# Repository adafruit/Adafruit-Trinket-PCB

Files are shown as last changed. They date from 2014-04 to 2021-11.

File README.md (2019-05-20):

## Adafruit Trinket 3.3 and 5V Microcontroller PCBs
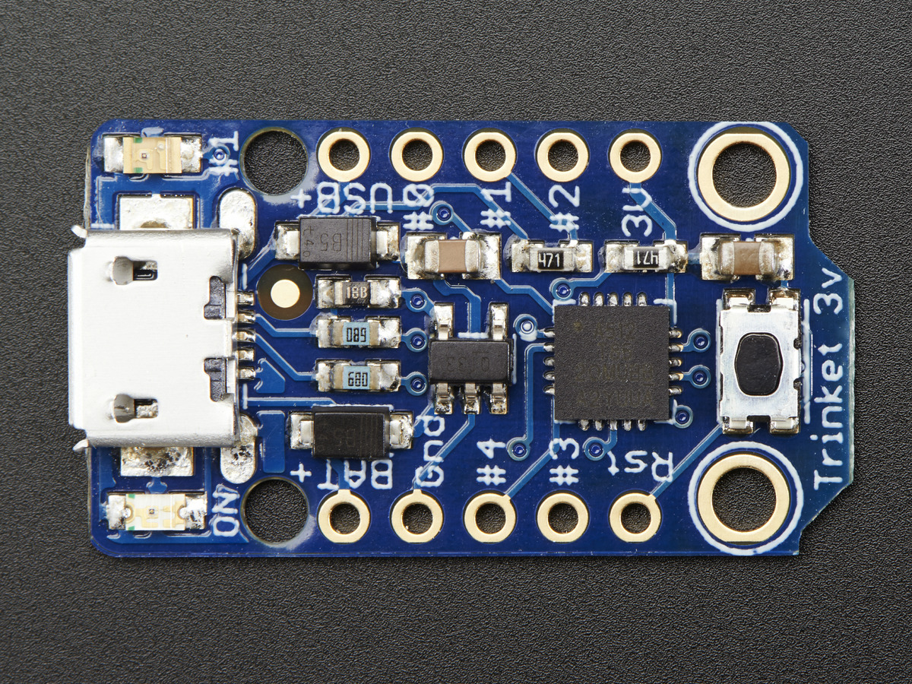
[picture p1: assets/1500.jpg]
&nbsp; 
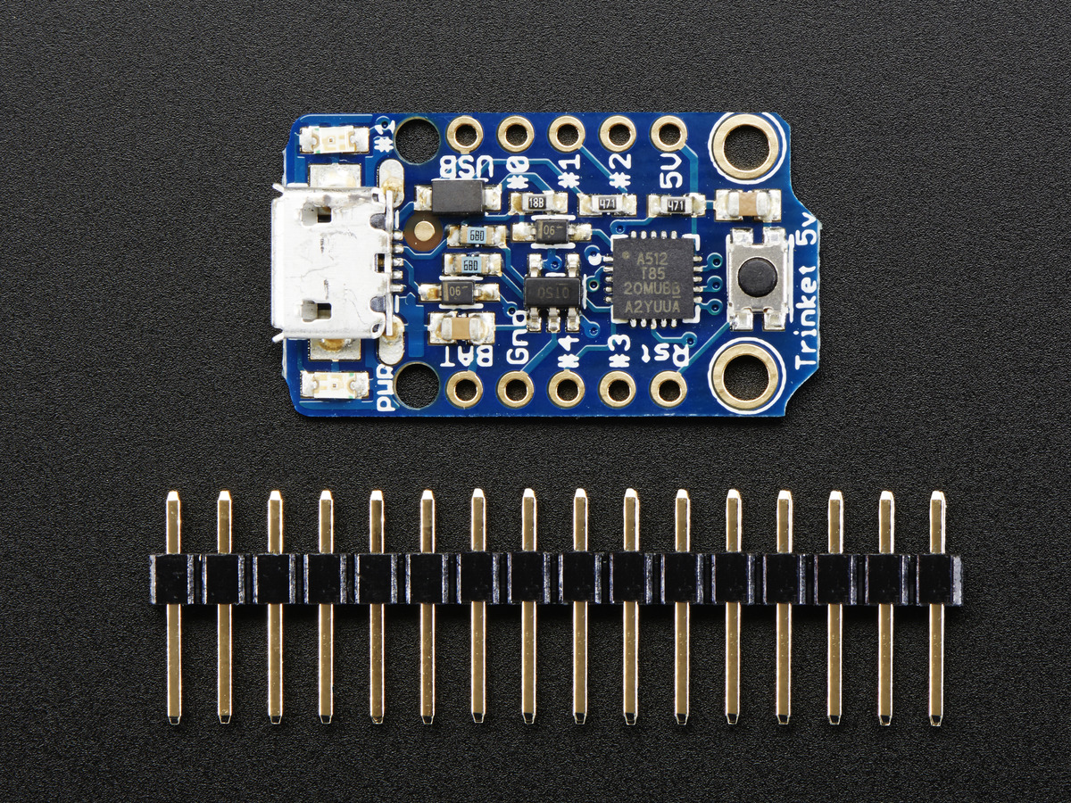
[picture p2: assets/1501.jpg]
<br />
Click to purchase from the Adafruit Shop:
- [Adafruit Trinket - Mini Microcontroller - 3.3V Logic - MicroUSB](https://www.adafruit.com/product/1500)
- [Adafruit Trinket - Mini Microcontroller - 5V Logic - MicroUSB](https://www.adafruit.com/product/1501)

Deprecation Warning: The Trinket bit-bang USB technique it uses doesn't work as well as it did in 2014, many modern computers won't work well. So while we still carry the Trinket so that people can maintain some older projects, we no longer recommend it. Please check out the **Trinket M0**. It has built-in USB, more capabilities, and is comparable in price!

Trinket may be small, but do not be fooled by its size! It's a tiny microcontroller board, built around the Atmel ATtiny85, a little chip with a lot of power. We wanted to design a microcontroller board that was small enough to fit into any project, and low cost enough to use without hesitation. Perfect for when you don't want to give up your expensive dev-board and you aren't willing to take apart the project you worked so hard to design. It's our lowest-cost arduino-IDE programmable board!

This is the CAD & PCB data for the Adafruit Trinket 3V & 5V. The PCB format is EagleCAD schematic and board layout
- https://www.adafruit.com/products/1500
- https://www.adafruit.com/products/1501

### License

Adafruit invests time and resources providing this open source design, please support Adafruit and open-source hardware by [purchasing products from Adafruit](https://www.adafruit.com)!

All text above must be included in any redistribution

Designed by Limor Fried/Ladyada for Adafruit Industries.
Creative Commons Attribution/Share-Alike, all text above must be included in any redistribution. 
See license.txt for additional information.

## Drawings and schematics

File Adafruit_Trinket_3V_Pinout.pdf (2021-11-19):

# Adafruit Trinket 3V

# https://www.adafruit.com/products/1500

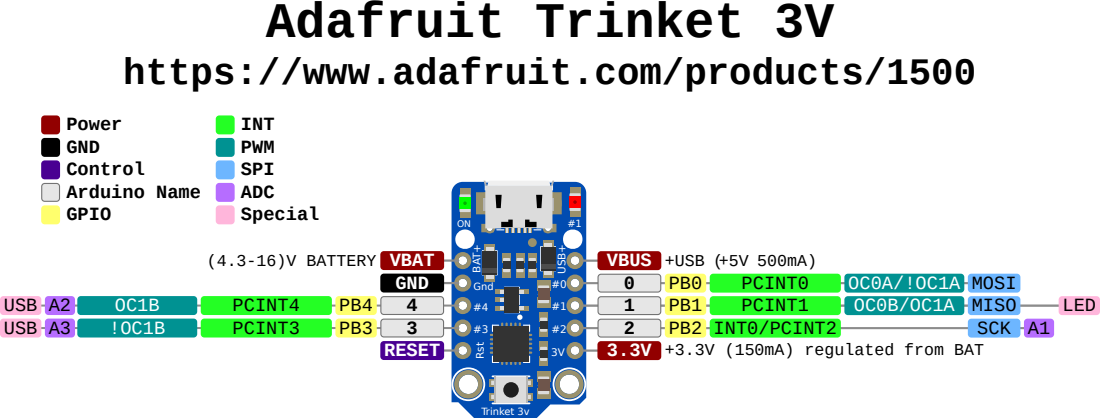
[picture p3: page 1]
#1 BAT+; USB+; Gnd; Rst; Trinket 3v; VBAT GND; RESET; VBUS; PCINT0; OC0A/!OC1A MOSI; PCINT1; OC0B/OC1A MISO; LED; PB2 INT0/PCINT2; SCK A1; USB A2; PCINT4; USB A3; PCINT3; Power GND Control Arduino Name GPIO; INT PWM SPI ADC Special; +USB (+5V 500mA); (4.3-16)V BATTERY

+3.3V (150mA) regulated from BAT

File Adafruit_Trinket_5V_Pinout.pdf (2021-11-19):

# Adafruit Trinket 5V

# https://www.adafruit.com/products/1501

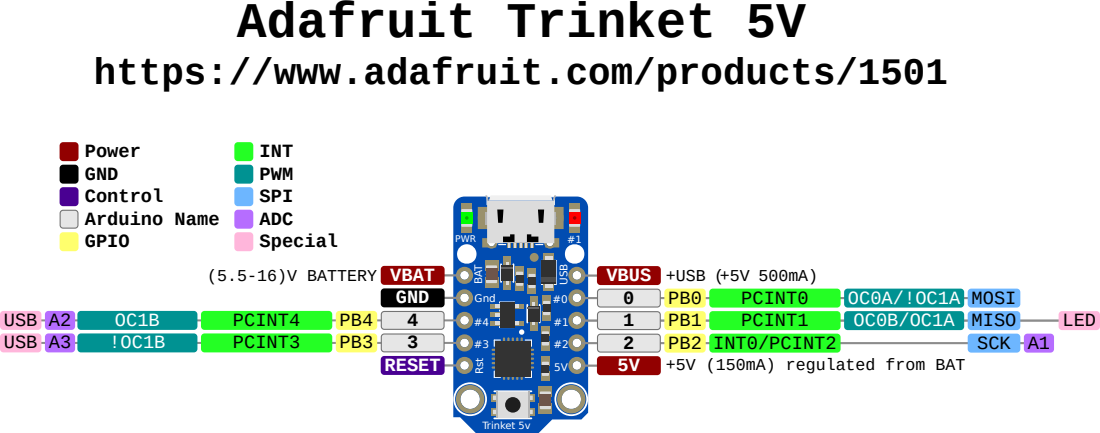
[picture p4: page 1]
PWR; #1 BAT; USB; Gnd; Rst #3; Trinket 5v; VBAT GND; USB A2; PCINT4; USB A3; PCINT3; RESET; VBUS; PCINT0; OC0A/!OC1A MOSI; PCINT1; OC0B/OC1A MISO; LED; PB2 INT0/PCINT2; SCK A1; Power GND Control Arduino Name GPIO; INT PWM SPI ADC Special; +USB (+5V 500mA); +5V (150mA) regulated from BAT; (5.5-16)V BATTERY

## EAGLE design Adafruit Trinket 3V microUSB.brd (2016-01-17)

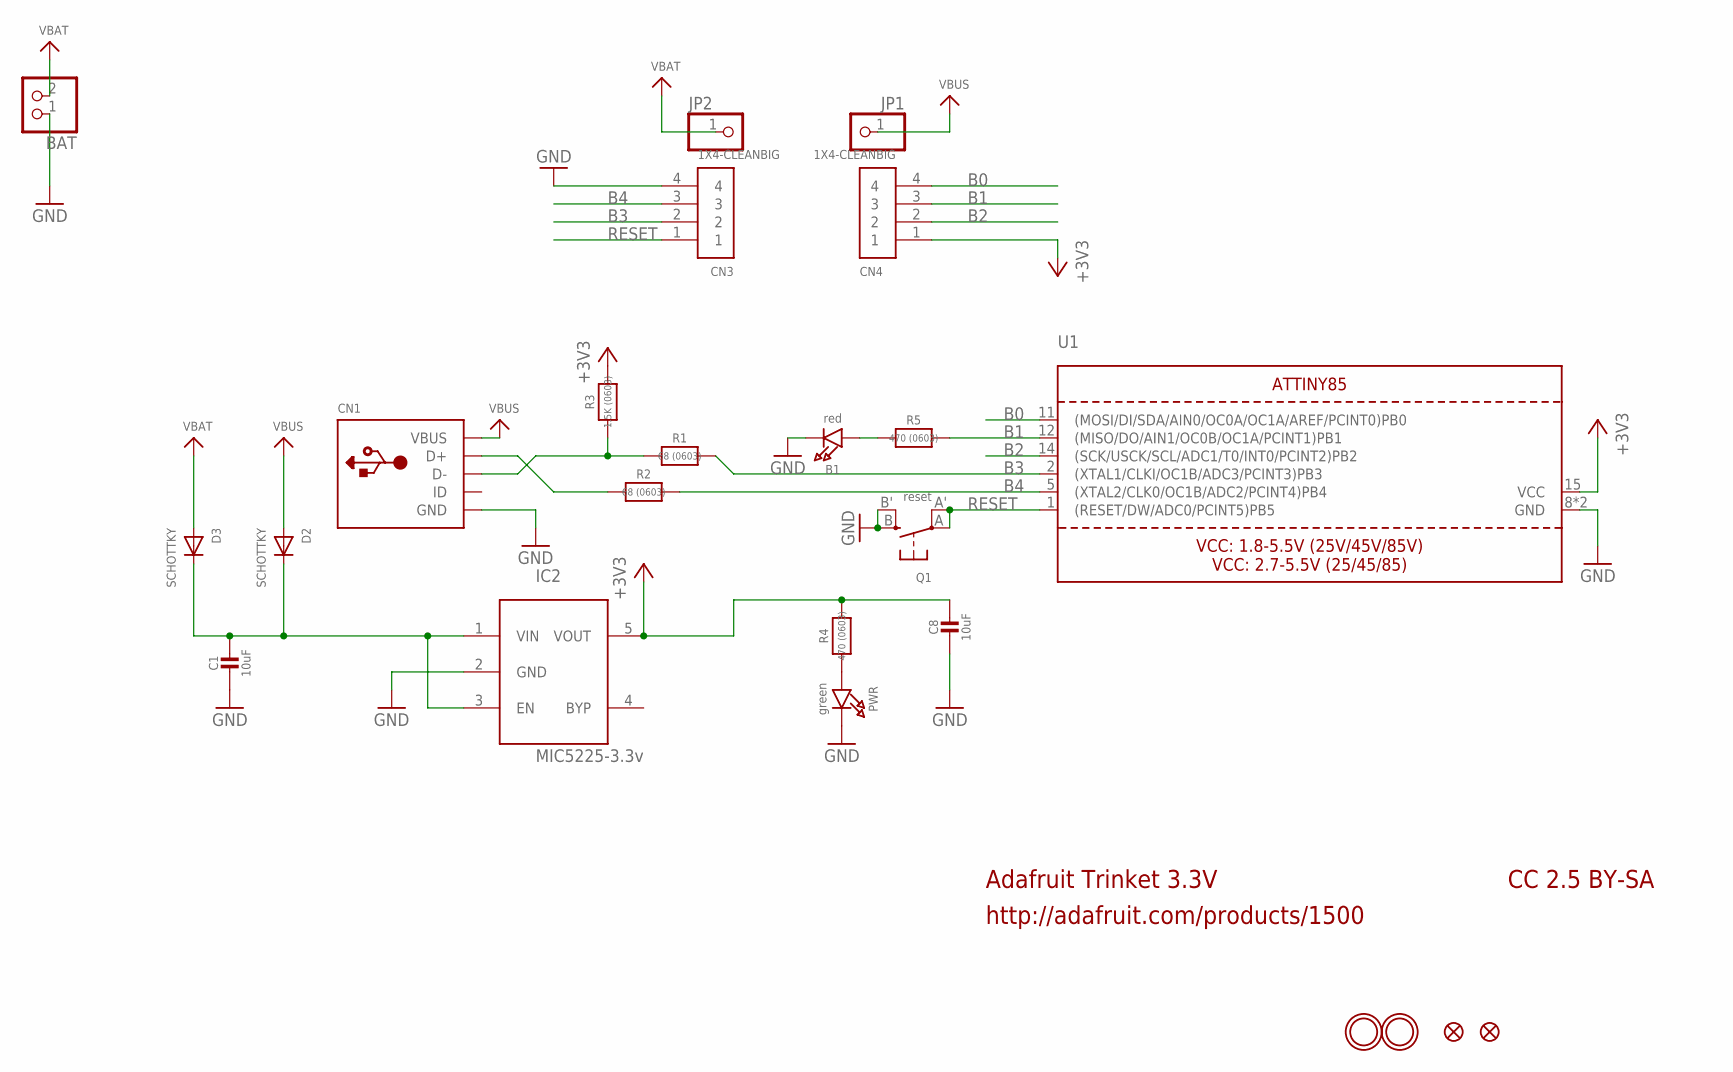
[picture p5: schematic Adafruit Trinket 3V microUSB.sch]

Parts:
B1: red; CHIPLED_0805_NOOUTLINE
BAT: CON_JST_PH_2PIN; JSTPH2
C1, C8: 10uF; 0805-NO
CN1: USBMICRO_20329; 4UCONN_20329
CN3, CN4: 1X4-CLEANBIG; 1X04-CLEANBIG
D2, D3: SCHOTTKY; SOD-123FL
IC2: MIC5225-3.3v; SOT23-5L
JP1, JP2: PINHD-1X1CB; 1X01-CLEANBIG
PWR: green; CHIPLED_0805_NOOUTLINE
Q1: reset; BTN_KMR2_4.6X2.8
R1, R2: 68 (0603); 0603-NO
R3: 1.5K (0603); 0603-NO
R4, R5: 470 (0603); 0603-NO
U1: ATTINY85; MLF20_4X4MM_0.5MM_ATMEL
U$1, U$6: FIDUCIAL""; FIDUCIAL_1MM
U$8, U$9: MOUNTINGHOLE2.0; MOUNTINGHOLE_2.0_PLATED

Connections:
+3V3: C8.1, CN4.1, IC2.5 (VOUT), R3.2, R4.2, U1.15 (VCC)
B0: CN4.4, U1.11 ((MOSI/DI/SDA/AIN0/OC0A/OC1A/AREF/PCINT0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)
B1: CN4.3, R5.2, U1.12 ((MISO/DO/AIN1/OC0B/OC1A/PCINT1)PB1)
B2: CN4.2, U1.14 ((SCK/USCK/SCL/ADC1/T0/INT0/PCINT2)PB2)
B3: CN3.2, R1.2, U1.2 ((XTAL1/CLKI/OC1B/ADC3/PCINT3)PB3)
B4: CN3.3, R2.2, U1.5 ((XTAL2/CLK0/OC1B/ADC2/PCINT4)PB4)
D+: CN1.D+, R2.1
D-: CN1.D-, R1.1, R3.1
GND: B1.C, BAT.1, C1.2, C8.2, CN1.BASE@1 (GND), CN1.BASE@2 (GND), CN1.GND, CN1.SPRT@1 (GND), CN1.SPRT@2 (GND), CN1.SPRT@3 (GND), CN1.SPRT@4 (GND), CN3.4, IC2.2 (GND), PWR.C, Q1.B (S), Q1.B' (S1), U1.8 (GND), U1.THERMAL (GND)
unnamed: B1.A, R5.1
unnamed: PWR.A, R4.1
unnamed: C1.1, D2.C, D3.C, IC2.1 (VIN), IC2.3 (EN)
RESET: CN3.1, Q1.A, Q1.A' (P1), U1.1 ((RESET/DW/ADC0/PCINT5)PB5)
VBAT: BAT.2, D3.A, JP2.1
VBUS: CN1.VBUS, D2.A, JP1.1

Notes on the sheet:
Adafruit Trinket 3.3V
http://adafruit.com/products/1500
CC 2.5 BY-SA

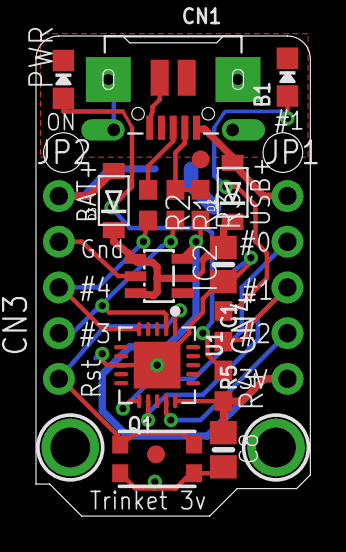
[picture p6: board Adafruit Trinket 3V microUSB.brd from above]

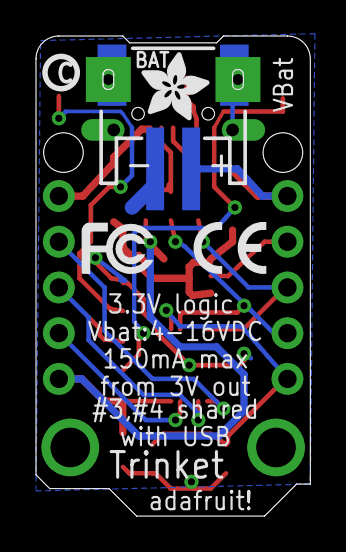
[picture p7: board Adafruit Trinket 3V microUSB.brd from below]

Board: 2 copper layers, 15.2 x 26.7 mm, 28 parts (5 on the bottom side), 15 nets.

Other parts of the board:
U$5: ADAFRUIT_3.5MM
U$12: PCBFEAT-REV-040
U$13: SYMBOL_FCC_TINY
U$14: SYMBOL_CE_TINY

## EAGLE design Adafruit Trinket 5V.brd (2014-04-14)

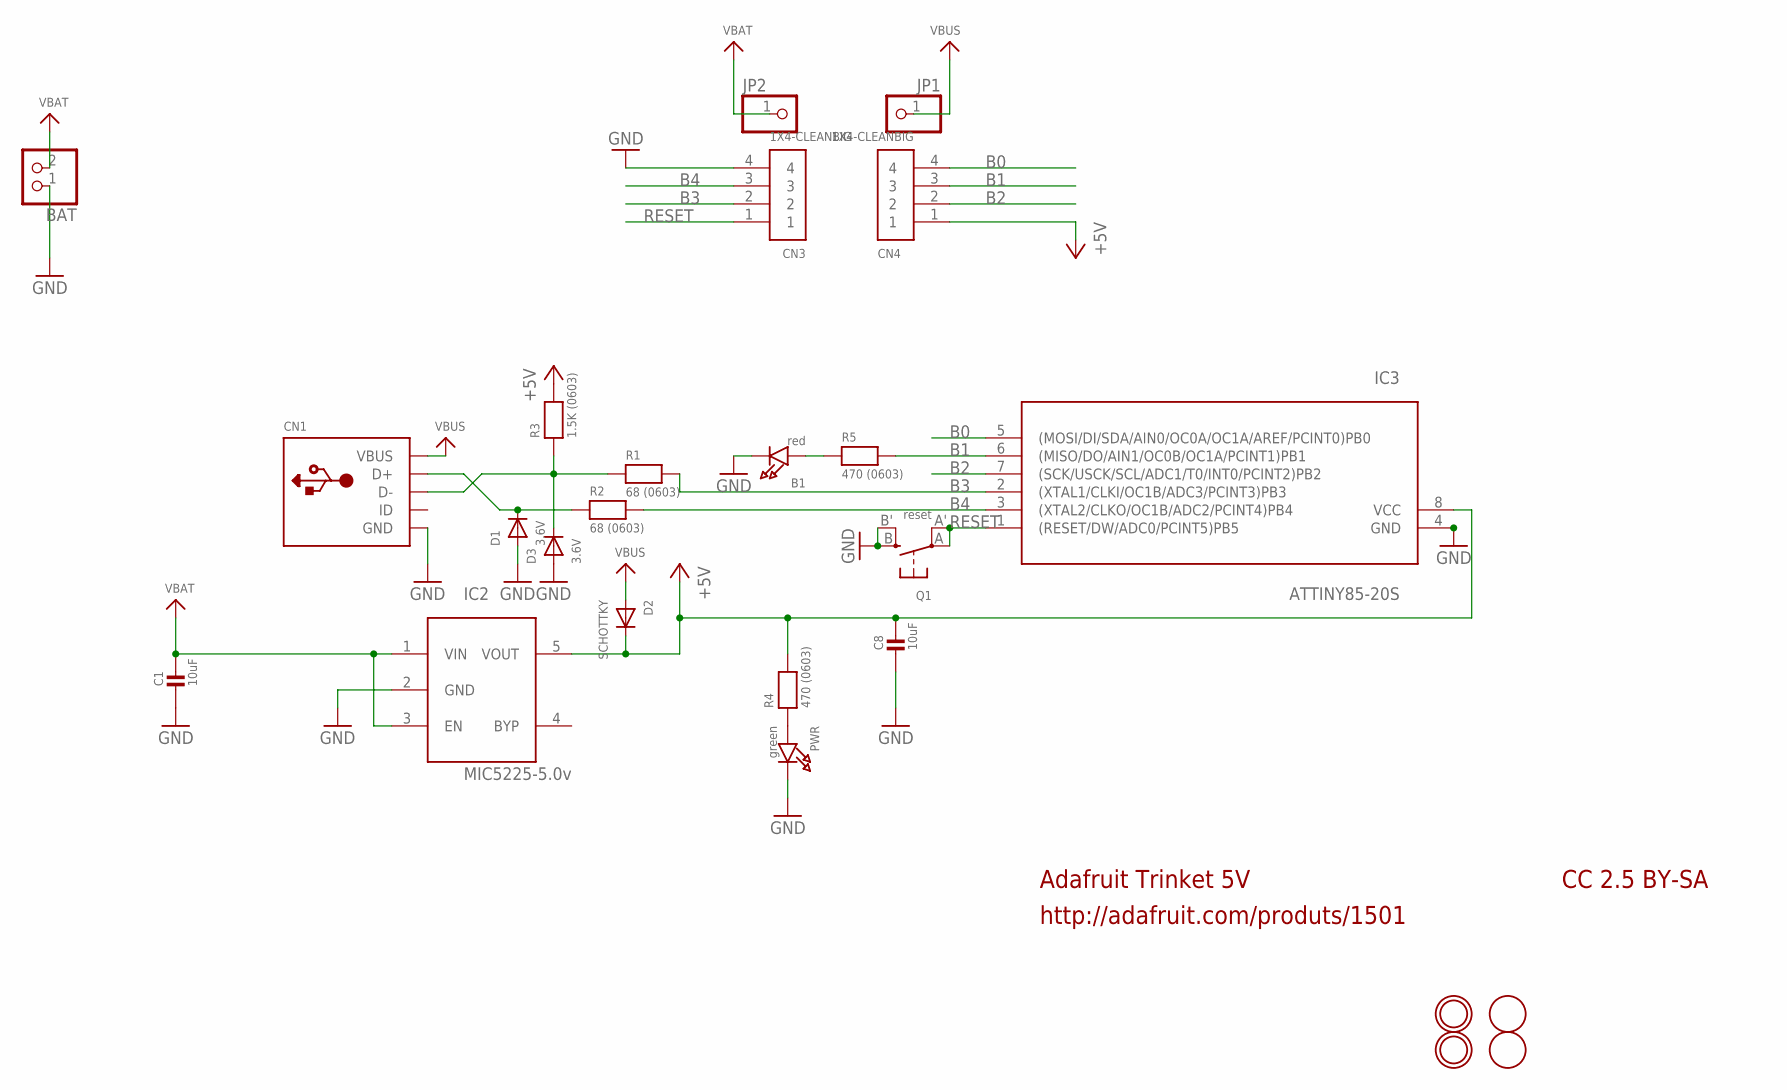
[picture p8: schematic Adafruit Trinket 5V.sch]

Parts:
B1: red; CHIPLED_0805_NOOUTLINE
BAT: CON_JST_PH_2PIN; JSTPH2
C1, C8: 10uF; 0805-NO
CN1: USBMINIB; USB-MINIB
CN3, CN4: 1X4-CLEANBIG; 1X04-CLEANBIG
D1, D3: 3.6V; SOD-323
D2: SCHOTTKY; SOD-123FL
IC2: MIC5225-5.0v; SOT23-5L
IC3: ATTINY85-20S; SOIC8
JP1, JP2: PINHD-1X1CB; 1X01-CLEANBIG
PWR: green; CHIPLED_0805_NOOUTLINE
Q1: reset; BTN_KMR2_4.6X2.8
R1, R2: 68 (0603); 0603-NO
R3: 1.5K (0603); 0603-NO
R4, R5: 470 (0603); 0603-NO
U$1, U$6: FIDUCIAL; FIDUCIAL_1MM
U$8, U$9: MOUNTINGHOLE2.0; MOUNTINGHOLE_2.0_PLATED

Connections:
+5V: C8.1, CN4.1, D2.C, IC2.5 (VOUT), IC3.8 (VCC), R3.2, R4.2
B0: CN4.4, IC3.5 ((MOSI/DI/SDA/AIN0/OC0A/OC1A/AREF/PCINT0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)
B1: CN4.3, IC3.6 ((MISO/DO/AIN1/OC0B/OC1A/PCINT1)PB1), R5.2
B2: CN4.2, IC3.7 ((SCK/USCK/SCL/ADC1/T0/INT0/PCINT2)PB2)
B3: CN3.2, IC3.2 ((XTAL1/CLKI/OC1B/ADC3/PCINT3)PB3), R1.2
B4: CN3.3, IC3.3 ((XTAL2/CLKO/OC1B/ADC2/PCINT4)PB4), R2.2
GND: B1.C, BAT.1, C1.2, C8.2, CN1.GND, CN1.GND1 (GND), CN1.GND2 (GND), CN1.GND3 (GND), CN1.GND4 (GND), CN3.4, D1.A, D3.A, IC2.2 (GND), IC3.4 (GND), PWR.C, Q1.B (S), Q1.B' (S1)
unnamed: B1.A, R5.1
unnamed: CN1.D+, D1.C, R2.1
unnamed: CN1.D-, D3.C, R1.1, R3.1
unnamed: PWR.A, R4.1
RESET: CN3.1, IC3.1 ((RESET/DW/ADC0/PCINT5)PB5), Q1.A, Q1.A' (P1)
VBAT: BAT.2, C1.1, IC2.1 (VIN), IC2.3 (EN), JP2.1
VBUS: CN1.VBUS, D2.A, JP1.1

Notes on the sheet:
Adafruit Trinket 5V
http://adafruit.com/produts/1501
CC 2.5 BY-SA

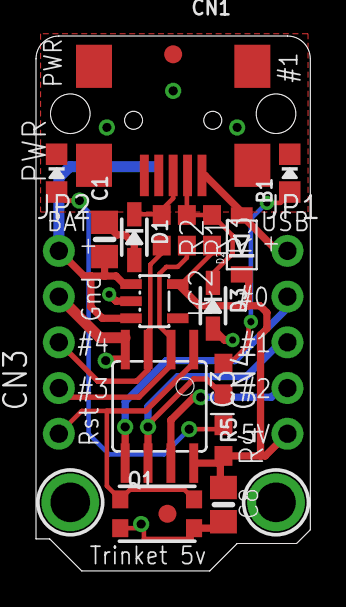
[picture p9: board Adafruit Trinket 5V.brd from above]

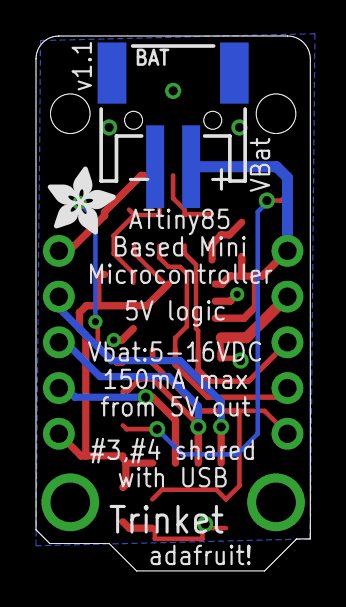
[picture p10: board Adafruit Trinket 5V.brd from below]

Board: 2 copper layers, 15.2 x 29.7 mm, 26 parts (2 on the bottom side), 14 nets.

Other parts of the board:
U$5: ADAFRUIT_3.5MM

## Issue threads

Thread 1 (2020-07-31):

challenge reaching low power levels

jerabaul29, 2020-07-31:
I know this is depreciated, but I just wanted to report / discuss some findings about the behavior of the board in low power applications. The reason why I ordered it in the first place was because I wanted to be able to have some super low power consumption during sleep. However, this did not work, as reported in this issue:

https://arduino.stackexchange.com/questions/39432/cannot-get-low-power-with-adafruit-trinket/77114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

It looks like the culprit is a diode + resistor on a USB port pin (this is a copy of the text in the linked issue):

"
The USB connector uses a resistor (1500 Ohms) against the 5V net and a 3.6 Volt Z-Diode on it's (D-)-Pin. In addition to the current that is drawn by the microcontroller, this part of the circuit draws some extra current. (5[V] - 3.6[V])/1500[ohm] = 0.0009333... ~= 0.001 [A].

Even though I'm not completely sure without making some tests, that seams plausible to me.

EDIT (Answer to the OPs comment below.)

The schematics uses a normal diode symbol but has a 3.6 Volt label next to it. I assume that it should be a Zener diode with a reverse voltage drop of 3.6 Volts. If I'm right, the Diode is used to limit the 5 Volts to 3.6 Volts (for what reason ever). The Zener Diode effectively limits the Voltage over it to 3.6 Volts. The rest of the voltage of 5 Volts must be dropped over the resistor. i.e. 5V - 3.6V = 1.4V. This voltage drop tells us by Ohms Law that the current through the resistor is:

```
I = U / R
I[A] = 1.4[V] / 1500[Ohm]  = (about) 1 mA.
```

This value is very reasonable for your observations and the current is drawn from the 5V connect, hence you can measure it, even if you would desolder the microcontroller.
"

- Can you confirm that this is well the cause?

- I am just curious: why was this setup used?

- Can you / maybe you should add some warnings / documentation about this, so that other 'naive' users like me who would like to achieve very low power from a simple development board do not choose this board / fall in the trap? :)

ladyada, 2020-07-31:
this is a simple, low cost level shifter for the USB pins so they are 5V. the 3V trinket does not have them

jerabaul29, 2020-07-31:
Thanks for the quick reply :) Ok, understood :) .

Closed 2020-07-31.

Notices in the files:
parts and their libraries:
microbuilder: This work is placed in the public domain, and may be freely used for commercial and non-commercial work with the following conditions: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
